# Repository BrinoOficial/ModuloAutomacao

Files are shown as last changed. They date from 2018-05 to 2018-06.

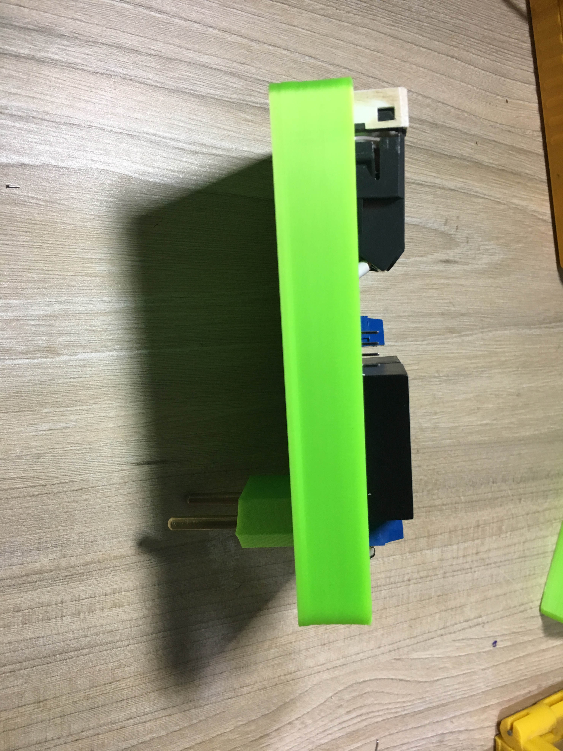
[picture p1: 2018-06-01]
Imagens/IMG-2597.JPG

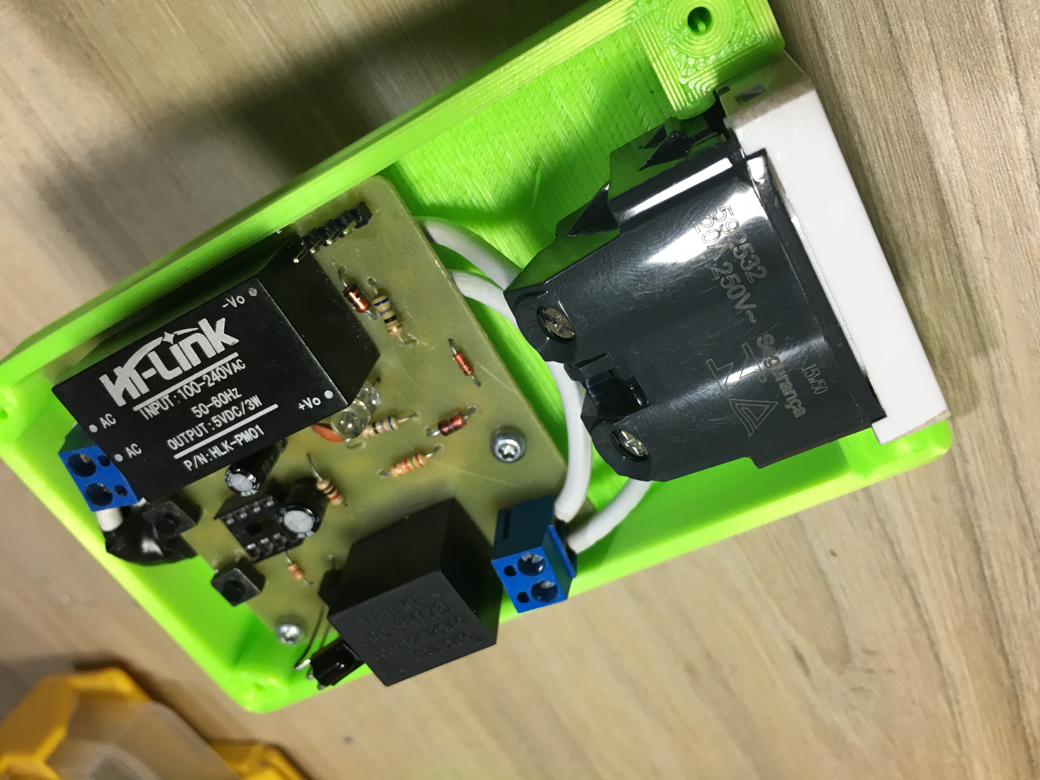
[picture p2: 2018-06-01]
Imagens/IMG-2596.jpg

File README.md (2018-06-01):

# ModuloAutomacao
Um módulo com base no franzininho para uma automação residencial simples e de baixo custo. A ideia é utilizar um controle remoto IR qualquer para poder ligar e deligar uma tomada. Com isso é possivel controlar coisas como lâmpadas e ventiladores com o clicar de um botão de sua TV.

## Quer saber como montar o projeto? Confira agora mesmo a [wiki](https://github.com/BrinoOficial/ModuloAutomacao/wiki)!

## Versão
Desenvolvido no Ubuntu 16.04 LTS 64Bits
* **Brino** - *3.0.1*
* **Arduino** - *2:1.0.5*
* **Eagle** - **
* **Fusion** - **

## Autores

* **Víctor Rodrigues Pacheco** - *Autor* - [granix3](https://github.com/granix3)
* **Gabriel Rodrigues Pacheco** - *Autor* - [GabrielRPacheco](https://github.com/gabrielRPacheco)
* **Mateus Berardo de Souza Terra** - *Autor* - [MatTerra](https://github.com/MatTerra)

Veja também a lista de [contributors](https://github.com/BrinoOficial/ModuloAutomacao/graphs/contributors).

## Licença

Este projeto está sob a licença do MIT - Veja em [LICENSE.md](LICENSE.md) arquivo para mais detalhes

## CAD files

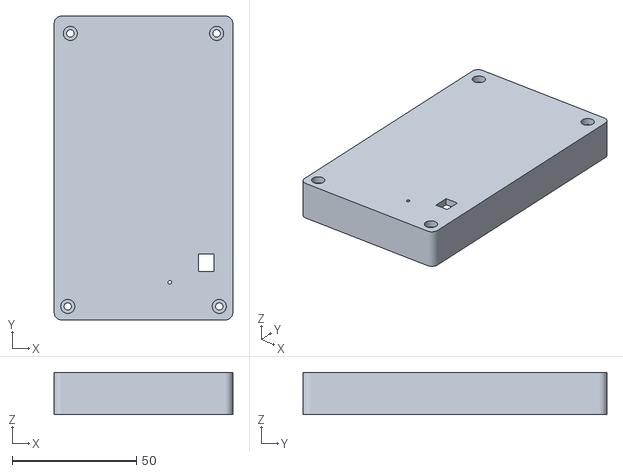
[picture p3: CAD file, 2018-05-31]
Case/Tampa.stl
71.9 x 122.3 x 17.0

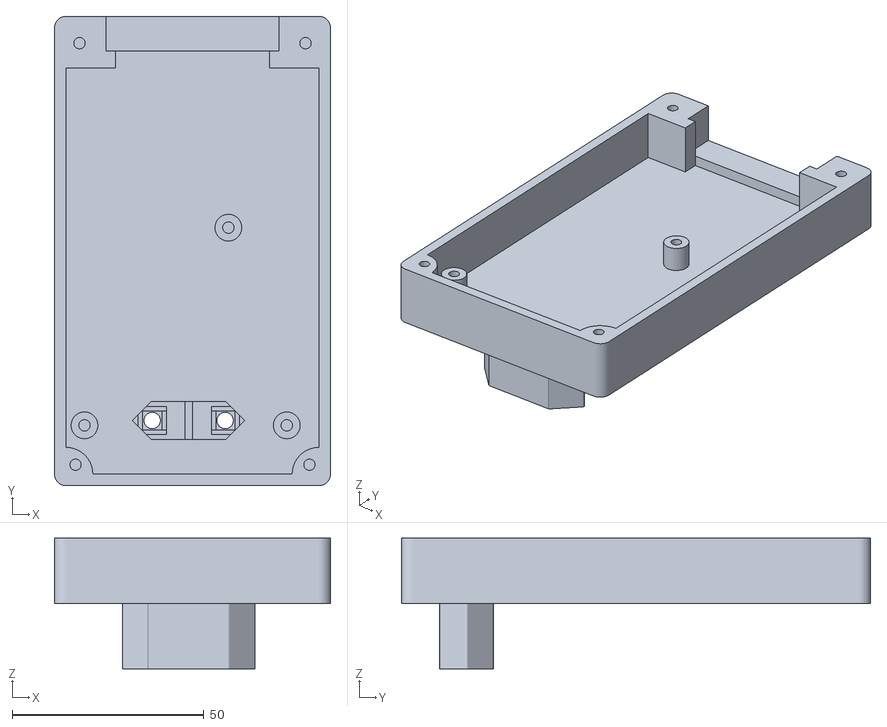
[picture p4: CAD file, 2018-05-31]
Case/Base.stl
71.9 x 122.3 x 34.0

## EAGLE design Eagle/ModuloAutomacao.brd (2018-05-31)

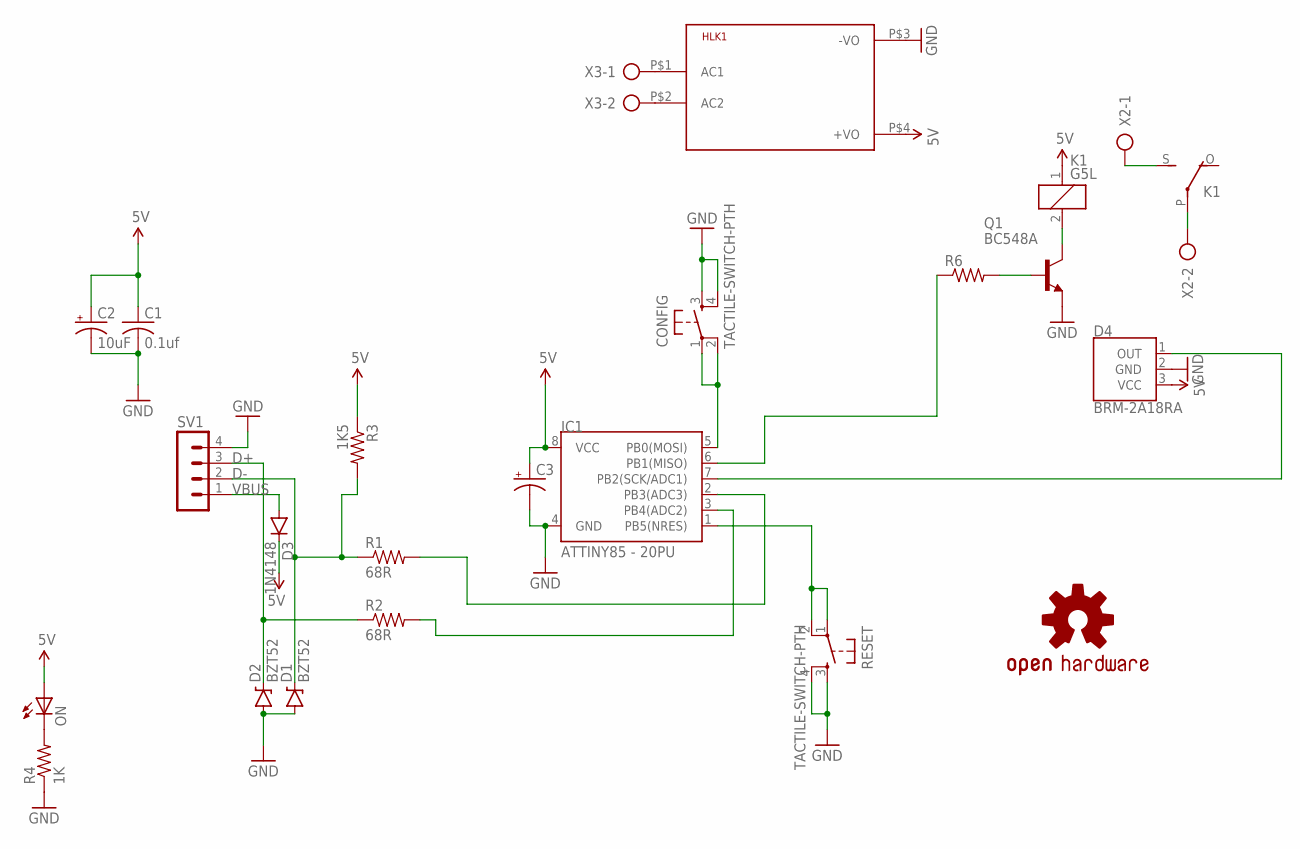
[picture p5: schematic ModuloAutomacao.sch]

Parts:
C1: 0.1uf; C025-025X050
C2: 10uF; E2,5-6E
C3: CPOL-USE1.8-4; E1,8-4
CONFIG: TACTILE-SWITCH-PTH; TAC-SWITCH-PTH
D1, D2: BZT52; DIODE-BZT52
D3: 1N4148; DIODE-1N4148
D4: BRM-2A18RA; BRM-2508
HLK1: HLK-PM013W; HLK-PM01
IC1: ATTINY85 - 20PU; DIP08
K1: G5L; G5LE
LOGO1: OSHW-LOGOM; OSHW-LOGO-M
ON: LED3MM
Q1: BC548A; TO92-EBC
R1, R2: 68R; AXIAL-0.4
R3: 1K5; AXIAL-0.4
R4: 1K; AXIAL-0.4
R6: R-US_0204/7; 0204/7
RESET: TACTILE-SWITCH-PTH; TAC-SWITCH-PTH
SV1: MA04-1
X2, X3: AK300/2

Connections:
5V: C1.1, C2.+, C3.+, D3.C, D4.3 (VCC), HLK1.P$4 (+VO), IC1.8 (VCC), K1.1, ON.A, R3.P$1 (1)
D+: D2.C, R2.P$1 (1), SV1.3
D-: D1.C, R1.P$1 (1), R3.P$2 (2), SV1.2
GND: C1.2, C2.-, C3.-, CONFIG.3, CONFIG.4, D1.A, D2.A, D4.2 (GND), HLK1.P$3 (-VO), IC1.4 (GND), Q1.E, R4.P$1 (1), RESET.3, RESET.4, SV1.4
unnamed: IC1.2 (PB3(ADC3)), R1.P$2 (2)
unnamed: IC1.6 (PB1(MISO)), R6.1
unnamed: CONFIG.1, CONFIG.2, IC1.5 (PB0(MOSI))
unnamed: D4.1 (OUT), IC1.7 (PB2(SCK/ADC1))
unnamed: IC1.3 (PB4(ADC2)), R2.P$2 (2)
unnamed: IC1.1 (PB5(NRES)), RESET.1, RESET.2
unnamed: K1.2, Q1.C
unnamed: Q1.B, R6.2
unnamed: HLK1.P$1 (AC1), X3.1
unnamed: HLK1.P$2 (AC2), X3.2
unnamed: K1.P, X2.2
unnamed: ON.K (C), R4.P$2 (2)
unnamed: K1.S, X2.1
VBUS: D3.A, SV1.1

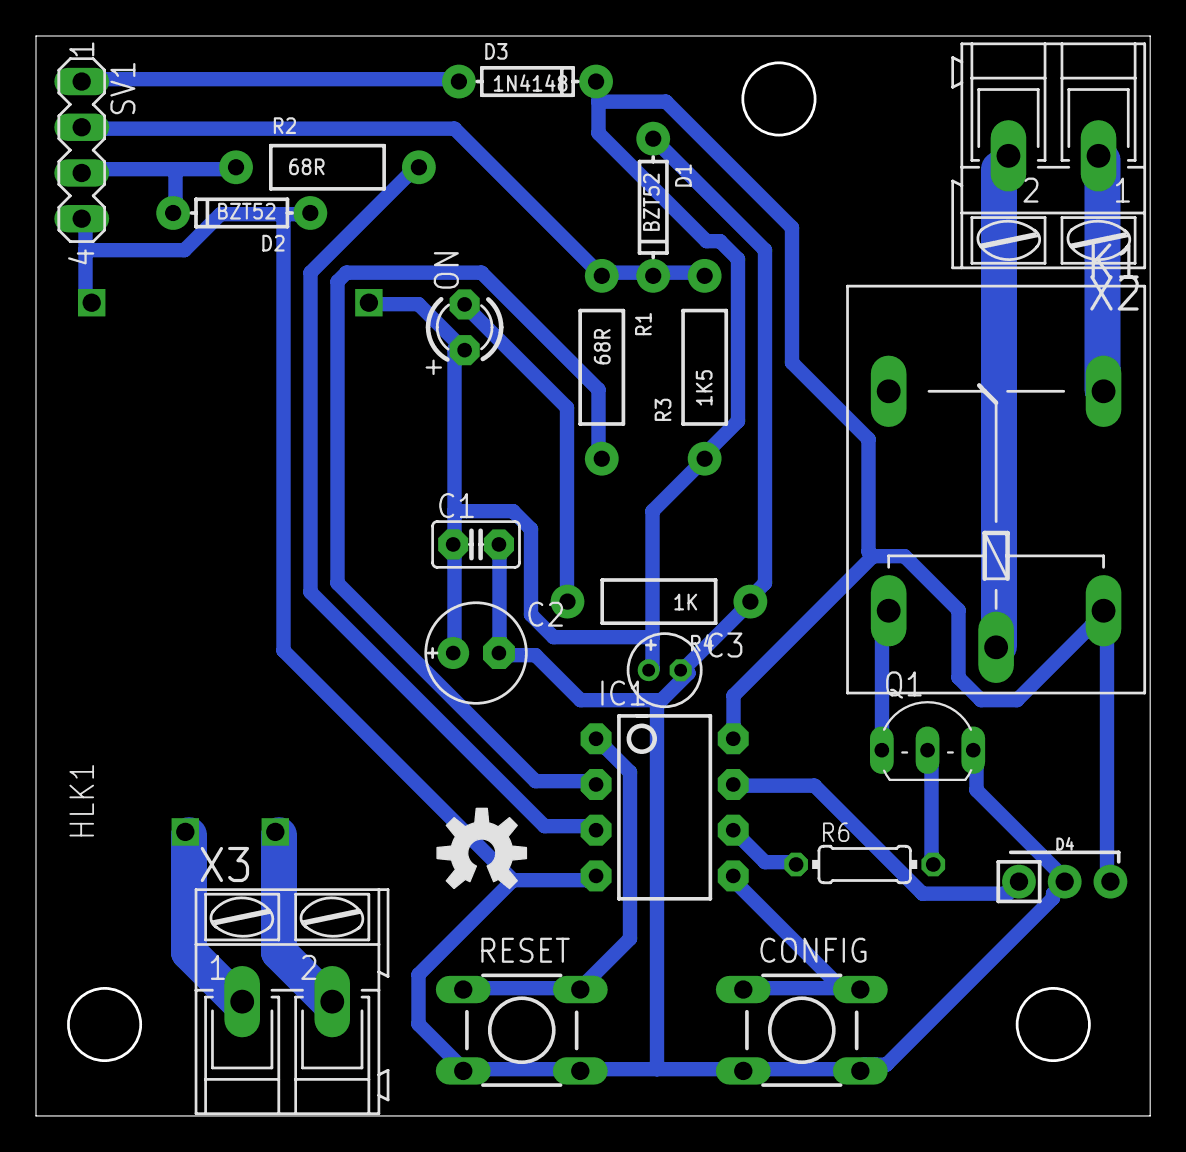
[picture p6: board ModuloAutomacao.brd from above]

Board: 2 copper layers, 61.9 x 60.0 mm, 23 parts (0 on the bottom side), 18 nets.

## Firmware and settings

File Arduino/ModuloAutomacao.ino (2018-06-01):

#include <IRLib.h>

#define MY_PROTOCOL NECX
#define menos 0xE0E0C43B
#define rele 13

IRrecv My_Receiver(2);
IRdecode My_Decoder; 

void setup(){ 
  My_Receiver.No_Output();
  My_Receiver.enableIRIn(); // Start the receiver
  pinMode(rele, OUTPUT);
  digitalWrite(rele, HIGH);
} 
 
void loop(){ 
    if(My_Receiver.GetResults(&My_Decoder)){
       My_Decoder.decode();
       if(My_Decoder.decode_type==MY_PROTOCOL){
          if(My_Decoder.value==menos)
            digitalWrite(rele, !(digitalRead(rele)));
          delay(200);
       }
       My_Receiver.resume();
    }
}

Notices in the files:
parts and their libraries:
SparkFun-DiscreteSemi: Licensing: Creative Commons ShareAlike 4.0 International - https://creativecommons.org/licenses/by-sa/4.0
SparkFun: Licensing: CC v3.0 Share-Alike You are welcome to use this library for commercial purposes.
